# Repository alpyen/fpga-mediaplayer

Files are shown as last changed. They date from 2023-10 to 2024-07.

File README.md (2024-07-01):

# Todos

Stuff that needs to be done, may be incomplete and not in order.

## Project

## HDL
- Video Driver
  - Fifo can contain bits after the last frame has been decoded due to the full byte padding
    - They need to be flushed out before marking playback as done.
      - We need to make sure video_play is low and we encounter an empty video fifo during decoding.
  - Test FSM and generated clock skew over four minutes
- Control Unit
  - Add Generic for the Base Address of the media file
    - This will be useful if we store a media file next to the bitstream or when we want to playback two files
  - Restructure to use less FFs
  - Add check for resolution and don't playback when it's incorrect

## Hardware
- Small LED Board v2
  - TPIC6A595 Open Drain Power Shift Register for low-side switching
  - 74HCT367 Hex-Buffer for level shifting and buffering
  - 74HCT595 instead of 74HC595 to get rid of the level shifters
  - Need to use one wire to disconnect shift register outputs to not overload on unknown power up state
  - No input resistors for shift registers as PMOD JB already has 200 Ohms
  - Pick new high-side MOSFET with low capacitance

## Vivado
- Change the board store in the project-tcl to be OS-independent
- Add custom command to write project tcl
  - add two scripts for loading and storing that just need to be sourced?
- Make sure assertions trigger on synthesis and implementation aswell

## Software
- Codec development
  - Wrap around 4 bit during encoding to save even more space
  - Check if the bitcrushing to 4 bits is correct and compresses uniforly
  - Add resolution to media file

## Documentation
- Write README on how to encode and load up the media file into the board's flash and play it back.

## Compatibility
- Check repo for Ubuntu Linux

# How to open with Vivado

The vivado project has to be regenerated from the project tcl file.
Simply run Vivado and use the tcl console to `cd` into the vivado subfolder of this repository and run `source ./fpga-mediaplayer.tcl`.

If you want to update the tcl file make sure to pass the correct project folder.
Vivado creates a subfolder with the name of the project by default which creates unnecessary nesting so you need to run the tcl command manually.

To write the project tcl make sure you're in the vivado subfolder and run this command: `write_project_tcl -target_proj_dir . fpga-mediaplayer.tcl -force`

Vivado stores absolute paths in the tcl comments, make sure to delete those if you don't want them public.
They can be found at the very top in the big comment.

# Project Goal

This is a personal project to deep dive into FPGA development and get in touch with every part of it
and to learn also a little bit about electrical engineering.

The vision is to have Basys3 board drive a selfmade LED matrix playing back a grayscale video and
outputting sound simultaneously.

Some of the decisions along the way are deliberately made in a non-optimal way such as writing
hdl descriptions for components that already exist to have it done myself and to constrain things.

Topics I want to cover (includes, but is not limited to):
- Develop a full FPGA project with everything necessary
- Write HDL and verify with testbenches
- Write packages and make them accessible
- Make use of existing IP
- Prototyping
- Schematics, Layouting and Manufacturing a PCB
- Interface with other onboard components such as memory
- Interface with prebuilt offboard components such as the Digilent I2S2 PMOD
- Interface with external offboard components such as the LED board
- Work within the limits of the given board such as the Digilent Basys3 (Artix7-35T)
  - 4MB Flash (2MB with configuration)
  - Available IO
  - Clock Speed to maintain realtime
- Software development
  - Codec for audio and video
- Miscellaneous
  - Organization of project structure and repository for Git
  - Documentation of the whole project

Please note that these constraints emerged from the components and devices I have at disposal.
This project could be done with greater resolution and sound output but the goal is to bring it up
and learn everything along the way, that's the reason behind the fullstack approach.

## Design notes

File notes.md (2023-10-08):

# Notes

Contains some thoughts over the development time of the project.

- Is it worth separating the SCK and RCK lines for the row selection shift registers?
  - They could be tied together, all that needs to be done is to clock once more because the data is behind one clock cycle, but it would save one line to the FPGA.
- The small LED board has the IRF4905 P-MOSFET on it, it seems like they are not a good fit, they will be exchanged for the bigger board.
  - They are on there because I ordered them thinking they were a good fit.
  - They work fine but will mess up operating the LEDs at the target voltage/current because the voltage drop changes heavily depending on the current running through it (dependant on how many LEDs are on)
  - Maybe I messed up with the test circuit, I will test again with 32 LEDs for the bigger version when designing that.
- Pullup for logic shifters is 10K which would lead to asymmetrical charge times for the shift registers.
  - See how long it actually takes to charge the lines up with 10K.
- Shift register is CMOS and the inputs have high-impedances so leaving out current limiting resistors.
  - However they are needed for N-MOSFET and P-MOSFET for example (to protect the device that is delivering the current).
  - I think they can be left out if the power supply delivers the current, and not a µC which has output current limitations.
- Pullups for Logic Shifter Drains / Shift Register Inputs are not suitable for the full size board.
  - It seems like it takes a few microseconds to charge up through a 10K, this will be a big problem depending on the video properties. 24fps / 8bpp will need much lower resistor values.
- The small board uses two shift registers for the column selection on purpose even though it could have been implemented with a single one.
  - The only difference to the full size board will be that we are wiring QC to SER from the first to the second register and this only works if the data is present on QC, instead of it only being present in the buffer stage as for example with QH'.

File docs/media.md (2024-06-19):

# Media

This document contains all the information about the mediatype used in this project.

First we identify natural constraints which emerge from the devices and peripheral used. Second we set boundary constraints to limit the scope of this project to something doable.
Lastly there is the specification of the media format.

- [Media](#media)
  - [Constraints](#constraints)
  - [Goals to achieve](#goals-to-achieve)
  - [Specification](#specification)
  - [Codec](#codec)
  - [File Structure](#file-structure)
    - [Header](#header)
    - [Data](#data)

## Constraints
- Digilent Basys3 (Artix7-35T)
- Flash Chip has 4MB/32Mbit of space available
  - Configuration uses 17,536,096 bits
  - with Configuration: 16,018,336 bits (~1,905K)
  - without Configuration: 33,554,432 bits (=4MB)
- Real time decodable for playback
- Do not use existing IP for direct codec implementation
- Decoder (Software counterpart) has to be implemented in hardware
  - therefore the encoder can't be too complex -> sacrificing on compression ratio

## Goals to achieve
- Implementation musn't be linked to loaded media
  - Design should be able to handle all kinds of media configurationswith greater memory capacity can be used easily
- preferrably load from detachable storage (SD-Card, USB-Stick)
- Video:
  - Length: about 4 minutes
  - Resolution: 32 x 24 pixels
  - Framerate: 24 fps
  - Grayscales: 16 shades (4 bits)
- Audio:
  - Length: about 4 minutes
  - Sample Rate: 44,100 Hz
  - Channels: Mono
  - Depth: 16 amplitudes (4 bits)

Calculated file size for uncompressed media:
- Video:
  - 4 mins * 60 * 32 * 24 pixels * 24 fps * 4 bits
  - 17,694,720 bits
- Audio:
  - 4 mins * 60 * 44,100 Hz * 1 * 4 bits
  - 42,336,000 bits
- Total:
  - 60,030,720 bits

Around 134 seconds (2:14) are available without any compression at all if the configuration is not present on the flash.

For the full four minutes, the target file has to be compressed down to 56% of the original file size which will be tough, but achievable.  With the configuration the target file size has to be 26% which is basically impossible for a simple and straight forward codec.

## Specification

## Codec

Since the bitwidth of the audio and video is so low the codec will be very simple.

The codec works by encoding differences over time so we compare the current sample to encode with the previous sample and write the data according to the table.

| Coding Table | Bit representation |
|---|---|
| Current Sample = Previous Sample | 0 |
| Current Sample = Previous Sample + 1 | 1 0 |
| Current Sample = Previous Sample - 1 | 1 1 0 |
| else (none of the above) | 1 1 1 x x x x |

So as an example if the previous sample is a `4` and the current sample is also a `4` we simply write a `0` bit into the encoded file.
For the case where the current sample is `5` we simply write the bits `1 0` into the file indicating that the sample is one higher than the previous saving two bits to the non-encoded counterpart.
For samples that differ too much (e.g. 2 or more) we write `1 1 1` to indicate that the next four bits `x x x x` will define a sample as a whole.

Analysis of some encoded files show that most differences are 0, +-1 and +-2. So even though the last case seems three bits longer than the non-encoded version, it happens less frequently.

For simplicity's sake audio and video will be padded to full bytes.
This only happens at the end of the file!

With the encoding out of the way, let's define a simple file header for the control unit to read out the metadata of the encoded media file.

## File Structure

### Header

``"A" (1B) #AudioBytes (4B) #VideoBytes (4B) "Z" (1B)``

- "A" (1 Byte):
  - This is part of the signature so the control unit can make sure that the contents at the given memory location (to look for the media) is actually a valid encoded file so we don't read garbage. Binary representation in 8-Bit ASCII.
- #AudioBytes (4 Bytes):
  - Little Endian encoded unsigned integer that contains the number of audio bytes contained within the media file.
- #VideoBytes (4 Bytes):
  - Little Endian encoded unsigned integer that contains the number of video bytes contained within the media file.
- "Z" (1 Byte):
  - The end of the signature, analog to the "A". Binary representation in 8-Bit ASCII.

As you can see the header contains no information about the actual encoding or the encoded format since this is irrelevant for the control unit which will only relay the data from the flash to the audio and video drivers.

This is also the key reason why the data is padded to full bytes since we expect the flash to return one byte at a time.

This allows us to vary the encoding without altering the control unit which only needs to read the header.

### Data

Audio and video data follow immediately the header with the complete audio first, then video.
The data is **not** interleaved.

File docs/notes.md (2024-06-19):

# Notes

Contains some thoughts over the development time of the project.

- Is it worth separating the SCK and RCK lines for the row selection shift registers?
  - They could be tied together, all that needs to be done is to clock once more because the data is behind one clock cycle, but it would save one line to the FPGA.
- The small LED board has the IRF4905 P-MOSFET on it, it seems like they are not a good fit, they will be exchanged for the bigger board.
  - They are on there because I ordered them thinking they were a good fit.
  - They work fine but will mess up operating the LEDs at the target voltage/current because the voltage drop changes heavily depending on the current running through it (dependant on how many LEDs are on)
  - Maybe I messed up with the test circuit, I will test again with 32 LEDs for the bigger version when designing that.
- Pullup for logic shifters is 10K which would lead to asymmetrical charge times for the shift registers.
  - See how long it actually takes to charge the lines up with 10K.
- Shift register is CMOS and the inputs have high-impedances so leaving out current limiting resistors.
  - However they are needed for N-MOSFET and P-MOSFET for example (to protect the device that is delivering the current).
  - I think they can be left out if the power supply delivers the current, and not a µC which has output current limitations.
- Pullups for Logic Shifter Drains / Shift Register Inputs are not suitable for the full size board.
  - It seems like it takes a few microseconds to charge up through a 10K, this will be a big problem depending on the video properties. 24fps / 8bpp will need much lower resistor values.
- The small board uses two shift registers for the column selection on purpose even though it could have been implemented with a single one.
  - The only difference to the full size board will be that we are wiring QC to SER from the first to the second register and this only works if the data is present on QC, instead of it only being present in the buffer stage as for example with QH'.
- I think it's worth dividing the memory access, the audio playback, the video playback and the control unit into different modules / entities so they can be interchanged for different implementations such as different memory storages (Flash, SD-Card, USB-Stick) or different codecs.
- The audio and video drivers will be fed through FIFOs and some additional control signals.
- The memory driver does not need a FIFO really.
- Pull all simulations signals to 'U' when they shouldn't be read instead of driving them with '0' for example?
- 'done' was registered in the spi_memory_driver. Is this really necessary? The simulation reacts badly on it, but it should work on hardware?
- Some testbenches could make use of vhdl2008 be pulling out the internal signals as aliases but we're sticking to Vivado's Default for now ('93?)
  - Instead of duplicating the code we simply route the signals outwards, this is ok because none of this will be synthesized so nothing will be wasted.
- I've implemented some ideas for audio codecs which isn't really something that's worth documenting the process of so I'll just implement one and maybe talk about a bit about the other ideas.
- The file header stores the sizes in 4 bytes even though the SPI flash can address at most 3 bytes.
  - This will result in resizing the audio_bytes and video_bytes signal in the control unit to match the 3 bytes address.
- We don't need to save the signature_begin and signature_end in the control unit as they will only be written and read once, it's a waste of flipflops.
- REQUEST_DATA in the control unit only dispatches a request if the read_audio_n_video is set accordingly.
  - This results in one clock cycle loss if for example audio is in order but the audio fifo is full.
  - Then we need to stall for one cycle for the read_audio_n_video signal to change.
  - Technically we could check in the previous state. Does this make sense hardwarewise and timingwise?
- FSM returns to idle when it's done reading audio and video but should only do so when the playback is stopped completely.
- If we calculate the schedule when the modules feed and eat data from the Fifos we could assume some FSM states.
  - Meaning that we for example don't need to check during bit decoding in audio if the Fifo is empty or not.
  - But for safety measures we will still to this, so it's safer when we expand it later down the line to higher quality samples.
  - This is important because the audio and video driver assume the Fifo only to run out **when there is no data left to play**.
- When playing back the 4 bit sample, we are only adding zeroes at the end.
  - We could make it louder by adding almost a bit on it so it maxes out the amplitude.
- CDC_HOLD_COUNT_WIDTH could be calculated more precisely.
  - We are potentially wasting one bit register space.
- The Audio Driver <-> I2S Master machines should never run out of sync that they need a timeout to resync.
- The codec.py calls ffmpeg with the filter `format=gray` instead of `hue=s=0` now. See if that makes a difference down the line.
  - Kept it gray for now since the intermediate files are smaller and will process faster.
- Control/AudioVideoDriver _done signal
  - It is combinational now, is this dangerous? The signal can only change when the state changes so it should work fine. No need to register, right?
- Check if the difference from the expected i2s clock and the actual datasheet clock results in the audio being player slower or faster.
- Do we need to check for reset /= '1' in the frame_buffer?
- The video driver will skew initially by almost up to a full millisecond for the big board, but that is okay, because this skew will not add up over time. The skew increases with resolution but since we don't intend to go higher we can ignore it.
  - However it would be nice to pre-decode the first frame so this skew does not exist.
- Would be nice to structure the project in a way that it's mostly vendor agnostic.

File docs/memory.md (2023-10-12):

# Memory

Notes on the memory driver interfacing with the onboard Macronix MX25L3233F ([Datasheet](https://www.macronix.com/Lists/Datasheet/Attachments/8933/MX25L3233F,%203V,%2032Mb,%20v1.7.pdf)).

> The Digilent Basys3 was manufactured with two different flash chips the other one being the Spansion S25FL032P. I happen to have the one with the Macronix on it. They are similar but not identical. The standard feature set is identical though, so the code can be used for both.

The onboard flash chip has different READ commands, to figure out which one we should use we have to determine
the minimum bandwidth from the media file.

The [Bandwidth minimum](memory.md#goals-to-achieve) is 161,928 bits/s which is 20,241 B/s.
Now we need to calculate the minimum clock frequency for the FPGA to achieve this bandwidth.

The standard READ command `(p.29, 10-7. Read Data Bytes (READ))` needs 8 cycles for the command, 24 cycles for the address and 8 cycles to return the data without pipelining which is 40 cycles in total.

Interfacing the flash chip with 50 MHz is rather dangerous, as stray capacitance (such as hands closeby) can actually disturb the connection and read faulty data, so we use a much safer clock of 10 MHz.
This is a clock that will safely work on-chip and on-board without any interference.

Assuming that we non-stop read data from the flash chip this means that we need to calculate: 10 MHz / 40 cycles/read = 250,000 reads/second.
Since one read will return a byte this will yield an average read-rate of 250 kB/s which is way more than we need.

Macronix offers a verilog simulation model for this chip, but for our use-case it is definitely overkill.
The model only needs to only support the basic READ command and initialize the storage with a given file, it can error out with unsupported commands.

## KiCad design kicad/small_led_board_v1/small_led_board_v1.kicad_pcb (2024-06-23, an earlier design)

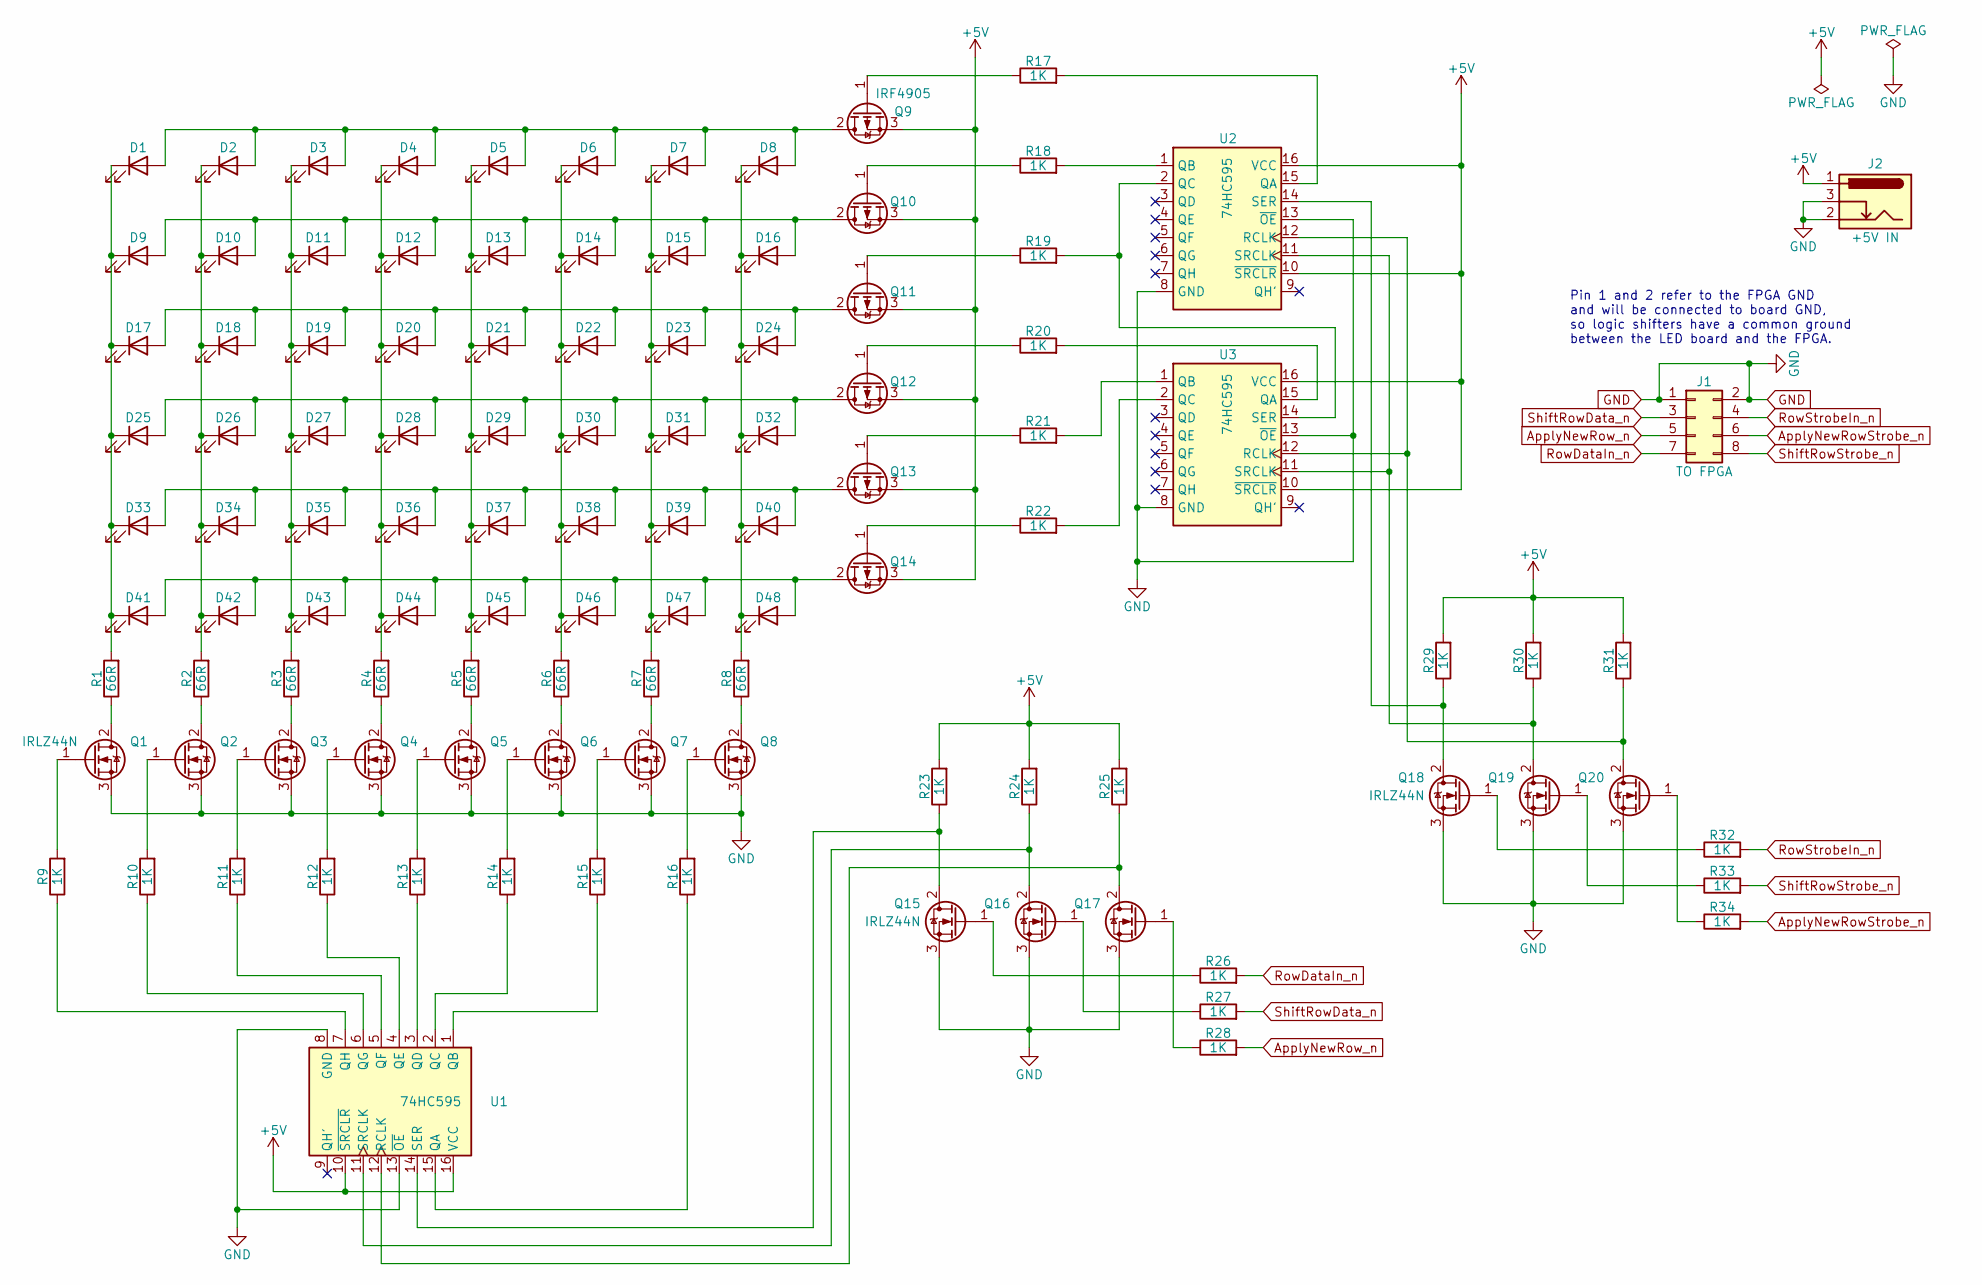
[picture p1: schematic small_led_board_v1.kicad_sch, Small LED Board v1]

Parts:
D1, D2, D3, D4, D5, D6, D7, D8, D9, D10, D11, D12, D13, D14, D15, D16, D17, D18, D19, D20, D21, D22, D23, D24, D25, D26, D27, D28, D29, D30, D31, D32, D33, D34, D35, D36, D37, D38, D39, D40, D41, D42, D43, D44, D45, D46, D47, D48: LED; LED_D5.0mm
J1: TO FPGA; PinSocket_2x04_P2.54mm_Horizontal
J2: +5V IN; BarrelJack_Horizontal
Q1, Q2, Q3, Q4, Q5, Q6, Q7, Q8, Q15, Q16, Q17, Q18, Q19, Q20: IRLZ44N; TO-220-3_Vertical
Q9, Q10, Q11, Q12, Q13, Q14: IRF4905; TO-220-3_Vertical
R1, R2, R3, R4, R5, R6, R7, R8: 66R; R_Axial_DIN0207_L6.3mm_D2.5mm_P7.62mm_Horizontal
R9, R10, R11, R12, R13, R14, R15, R16, R17, R18, R19, R20, R21, R22, R23, R24, R25, R26, R27, R28, R29, R30, R31, R32, R33, R34: 1K; R_Axial_DIN0207_L6.3mm_D2.5mm_P7.62mm_Horizontal
U1, U2, U3: 74HC595; DIP-16_W7.62mm

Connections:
+5V: J2.1, Q9.3 (S), Q10.3 (S), Q11.3 (S), Q12.3 (S), Q13.3 (S), Q14.3 (S), R23.2, R24.2, R25.2, R29.2, R30.2, R31.2, U1.10 (~SRCLR), U1.16 (VCC), U2.10 (~SRCLR), U2.16 (VCC), U3.10 (~SRCLR), U3.16 (VCC)
ApplyNewRowStrobe_n: J1.6, R34.2
ApplyNewRow_n: J1.5, R28.2
GND: J1.1, J1.2, J2.2, J2.3, Q1.3 (S), Q2.3 (S), Q3.3 (S), Q4.3 (S), Q5.3 (S), Q6.3 (S), Q7.3 (S), Q8.3 (S), Q15.3 (S), Q16.3 (S), Q17.3 (S), Q18.3 (S), Q19.3 (S), Q20.3 (S), U1.8 (GND), U1.13 (~OE), U2.8 (GND), U2.13 (~OE), U3.8 (GND), U3.13 (~OE)
unnamed: D1.2 (A), D2.2 (A), D3.2 (A), D4.2 (A), D5.2 (A), D6.2 (A), D7.2 (A), D8.2 (A), Q9.2 (D)
unnamed: D1.1 (K), D9.1 (K), D17.1 (K), D25.1 (K), D33.1 (K), D41.1 (K), R1.2
unnamed: D9.2 (A), D10.2 (A), D11.2 (A), D12.2 (A), D13.2 (A), D14.2 (A), D15.2 (A), D16.2 (A), Q10.2 (D)
unnamed: D2.1 (K), D10.1 (K), D18.1 (K), D26.1 (K), D34.1 (K), D42.1 (K), R2.2
unnamed: D3.1 (K), D11.1 (K), D19.1 (K), D27.1 (K), D35.1 (K), D43.1 (K), R3.2
unnamed: D4.1 (K), D12.1 (K), D20.1 (K), D28.1 (K), D36.1 (K), D44.1 (K), R4.2
unnamed: D5.1 (K), D13.1 (K), D21.1 (K), D29.1 (K), D37.1 (K), D45.1 (K), R5.2
unnamed: D6.1 (K), D14.1 (K), D22.1 (K), D30.1 (K), D38.1 (K), D46.1 (K), R6.2
unnamed: D7.1 (K), D15.1 (K), D23.1 (K), D31.1 (K), D39.1 (K), D47.1 (K), R7.2
unnamed: D8.1 (K), D16.1 (K), D24.1 (K), D32.1 (K), D40.1 (K), D48.1 (K), R8.2
unnamed: D17.2 (A), D18.2 (A), D19.2 (A), D20.2 (A), D21.2 (A), D22.2 (A), D23.2 (A), D24.2 (A), Q11.2 (D)
unnamed: D25.2 (A), D26.2 (A), D27.2 (A), D28.2 (A), D29.2 (A), D30.2 (A), D31.2 (A), D32.2 (A), Q12.2 (D)
unnamed: D33.2 (A), D34.2 (A), D35.2 (A), D36.2 (A), D37.2 (A), D38.2 (A), D39.2 (A), D40.2 (A), Q13.2 (D)
unnamed: D41.2 (A), D42.2 (A), D43.2 (A), D44.2 (A), D45.2 (A), D46.2 (A), D47.2 (A), D48.2 (A), Q14.2 (D)
unnamed: Q1.2 (D), R1.1
unnamed: Q1.1 (G), R9.2
unnamed: Q2.2 (D), R2.1
unnamed: Q2.1 (G), R10.2
unnamed: Q3.2 (D), R3.1
unnamed: Q3.1 (G), R11.2
unnamed: Q4.2 (D), R4.1
unnamed: Q4.1 (G), R12.2
unnamed: Q5.2 (D), R5.1
unnamed: Q5.1 (G), R13.2
unnamed: Q6.2 (D), R6.1
unnamed: Q6.1 (G), R14.2
unnamed: Q7.2 (D), R7.1
unnamed: Q7.1 (G), R15.2
unnamed: Q8.2 (D), R8.1
unnamed: Q8.1 (G), R16.2
unnamed: Q9.1 (G), R17.1
unnamed: Q10.1 (G), R18.1
unnamed: Q11.1 (G), R19.1
unnamed: Q12.1 (G), R20.1
unnamed: Q13.1 (G), R21.1
unnamed: Q14.1 (G), R22.1
unnamed: Q15.2 (D), R23.1, U1.14 (SER)
unnamed: Q15.1 (G), R26.1
unnamed: Q16.2 (D), R24.1, U1.11 (SRCLK)
unnamed: Q16.1 (G), R27.1
unnamed: Q17.2 (D), R25.1, U1.12 (RCLK)
unnamed: Q17.1 (G), R28.1
unnamed: Q18.2 (D), R29.1, U2.14 (SER)
unnamed: Q18.1 (G), R32.1
unnamed: Q19.2 (D), R30.1, U2.11 (SRCLK), U3.11 (SRCLK)
unnamed: Q19.1 (G), R33.1
unnamed: Q20.2 (D), R31.1, U2.12 (RCLK), U3.12 (RCLK)
unnamed: Q20.1 (G), R34.1
unnamed: R16.1, U1.15 (QA)
unnamed: R15.1, U1.1 (QB)
unnamed: R14.1, U1.2 (QC)
unnamed: R13.1, U1.3 (QD)
unnamed: R12.1, U1.4 (QE)
unnamed: R11.1, U1.5 (QF)
unnamed: R10.1, U1.6 (QG)
unnamed: R9.1, U1.7 (QH)
unnamed: R17.2, U2.15 (QA)
unnamed: R18.2, U2.1 (QB)
unnamed: R19.2, U2.2 (QC), U3.14 (SER)
unnamed: R20.2, U3.15 (QA)
unnamed: R21.2, U3.1 (QB)
unnamed: R22.2, U3.2 (QC)
RowDataIn_n: J1.7, R26.2
RowStrobeIn_n: J1.4, R32.2
ShiftRowData_n: J1.3, R27.2
ShiftRowStrobe_n: J1.8, R33.2

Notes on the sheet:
Pin 1 and 2 refer to the FPGA GND and will be connected to board GND, so logic shifters have a common ground between the LED board and the FPGA.

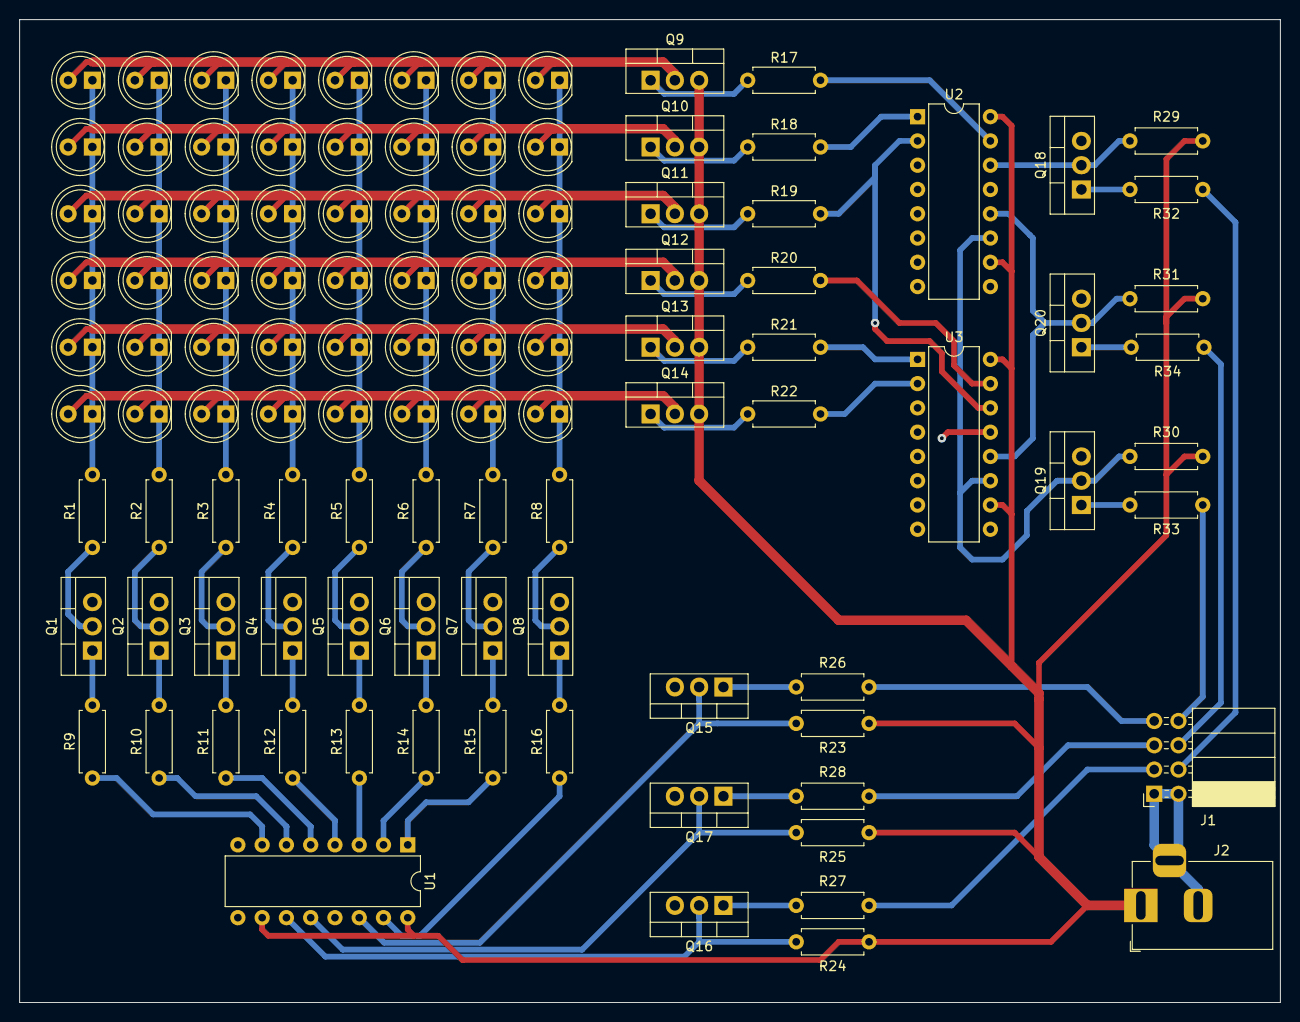
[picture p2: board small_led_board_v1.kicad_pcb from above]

Board: 2 copper layers, 132.0 x 102.9 mm, 107 parts (0 on the bottom side), 70 nets.

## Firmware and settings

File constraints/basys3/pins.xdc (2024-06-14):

## Clock signal
set_property -dict { PACKAGE_PIN W5   IOSTANDARD LVCMOS33 } [get_ports clock100mhz];

## Switches
# set_property -dict { PACKAGE_PIN V17   IOSTANDARD LVCMOS33 } [get_ports {sw[0]}];
# set_property -dict { PACKAGE_PIN V16   IOSTANDARD LVCMOS33 } [get_ports {sw[1]}];
# set_property -dict { PACKAGE_PIN W16   IOSTANDARD LVCMOS33 } [get_ports {sw[2]}];
# set_property -dict { PACKAGE_PIN W17   IOSTANDARD LVCMOS33 } [get_ports {sw[3]}];
# set_property -dict { PACKAGE_PIN W15   IOSTANDARD LVCMOS33 } [get_ports {sw[4]}];
# set_property -dict { PACKAGE_PIN V15   IOSTANDARD LVCMOS33 } [get_ports {sw[5]}];
# set_property -dict { PACKAGE_PIN W14   IOSTANDARD LVCMOS33 } [get_ports {sw[6]}];
# set_property -dict { PACKAGE_PIN W13   IOSTANDARD LVCMOS33 } [get_ports {sw[7]}];
# set_property -dict { PACKAGE_PIN V2    IOSTANDARD LVCMOS33 } [get_ports {sw[8]}];
# set_property -dict { PACKAGE_PIN T3    IOSTANDARD LVCMOS33 } [get_ports {sw[9]}];
# set_property -dict { PACKAGE_PIN T2    IOSTANDARD LVCMOS33 } [get_ports {sw[10]}];
# set_property -dict { PACKAGE_PIN R3    IOSTANDARD LVCMOS33 } [get_ports {sw[11]}];
# set_property -dict { PACKAGE_PIN W2    IOSTANDARD LVCMOS33 } [get_ports {sw[12]}];
# set_property -dict { PACKAGE_PIN U1    IOSTANDARD LVCMOS33 } [get_ports {sw[13]}];
# set_property -dict { PACKAGE_PIN T1    IOSTANDARD LVCMOS33 } [get_ports {sw[14]}];
# set_property -dict { PACKAGE_PIN R2    IOSTANDARD LVCMOS33 } [get_ports {sw[15]}];


## LEDs
# You cannot leave driven top level pins unplaced, but we need spi_sclk for the testbench.
# Since we don't need it on the Artix7 (as it is accessed through STARTUPE2) we simply
# output it somewhere where it doesn't really bother us.
set_property -dict { PACKAGE_PIN U16   IOSTANDARD LVCMOS33 } [get_ports spi_sclk]; # led0
# set_property -dict { PACKAGE_PIN E19   IOSTANDARD LVCMOS33 } [get_ports {led[1]}];
# set_property -dict { PACKAGE_PIN U19   IOSTANDARD LVCMOS33 } [get_ports {led[2]}];
# set_property -dict { PACKAGE_PIN V19   IOSTANDARD LVCMOS33 } [get_ports {led[3]}];
# set_property -dict { PACKAGE_PIN W18   IOSTANDARD LVCMOS33 } [get_ports {led[4]}];
# set_property -dict { PACKAGE_PIN U15   IOSTANDARD LVCMOS33 } [get_ports {led[5]}];
# set_property -dict { PACKAGE_PIN U14   IOSTANDARD LVCMOS33 } [get_ports {led[6]}];
# set_property -dict { PACKAGE_PIN V14   IOSTANDARD LVCMOS33 } [get_ports {led[7]}];
# set_property -dict { PACKAGE_PIN V13   IOSTANDARD LVCMOS33 } [get_ports {led[8]}];
# set_property -dict { PACKAGE_PIN V3    IOSTANDARD LVCMOS33 } [get_ports {led[9]}];
# set_property -dict { PACKAGE_PIN W3    IOSTANDARD LVCMOS33 } [get_ports {led[10]}];
# set_property -dict { PACKAGE_PIN U3    IOSTANDARD LVCMOS33 } [get_ports {led[11]}];
# set_property -dict { PACKAGE_PIN P3    IOSTANDARD LVCMOS33 } [get_ports {led[12]}];
# set_property -dict { PACKAGE_PIN N3    IOSTANDARD LVCMOS33 } [get_ports {led[13]}];
# set_property -dict { PACKAGE_PIN P1    IOSTANDARD LVCMOS33 } [get_ports {led[14]}];
# set_property -dict { PACKAGE_PIN L1    IOSTANDARD LVCMOS33 } [get_ports {led[15]}];


##7 Segment Display
# set_property -dict { PACKAGE_PIN W7   IOSTANDARD LVCMOS33 } [get_ports {seg[0]}];
# set_property -dict { PACKAGE_PIN W6   IOSTANDARD LVCMOS33 } [get_ports {seg[1]}];
# set_property -dict { PACKAGE_PIN U8   IOSTANDARD LVCMOS33 } [get_ports {seg[2]}];
# set_property -dict { PACKAGE_PIN V8   IOSTANDARD LVCMOS33 } [get_ports {seg[3]}];
# set_property -dict { PACKAGE_PIN U5   IOSTANDARD LVCMOS33 } [get_ports {seg[4]}];
# set_property -dict { PACKAGE_PIN V5   IOSTANDARD LVCMOS33 } [get_ports {seg[5]}];
# set_property -dict { PACKAGE_PIN U7   IOSTANDARD LVCMOS33 } [get_ports {seg[6]}];

# set_property -dict { PACKAGE_PIN V7   IOSTANDARD LVCMOS33 } [get_ports dp];

# set_property -dict { PACKAGE_PIN U2   IOSTANDARD LVCMOS33 } [get_ports {an[0]}];
# set_property -dict { PACKAGE_PIN U4   IOSTANDARD LVCMOS33 } [get_ports {an[1]}];
# set_property -dict { PACKAGE_PIN V4   IOSTANDARD LVCMOS33 } [get_ports {an[2]}];
# set_property -dict { PACKAGE_PIN W4   IOSTANDARD LVCMOS33 } [get_ports {an[3]}];


##Buttons
# set_property -dict { PACKAGE_PIN U18   IOSTANDARD LVCMOS33 } [get_ports btnC];
# set_property -dict { PACKAGE_PIN T18   IOSTANDARD LVCMOS33 } [get_ports btnU];
set_property -dict { PACKAGE_PIN W19   IOSTANDARD LVCMOS33 } [get_ports reset]; # btnL
set_property -dict { PACKAGE_PIN T17   IOSTANDARD LVCMOS33 } [get_ports start_button]; # btnR
# set_property -dict { PACKAGE_PIN U17   IOSTANDARD LVCMOS33 } [get_ports btnD];
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

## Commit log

2023-09-28 small_led_board: Update schematics
    [small_led_board.kicad_pcb, small_led_board.kicad_sch]
2023-09-28 small_led_board: Schematic updated, DRC pass
    - Schematic passes DRC check without any issue
    - LED resistors still need to be calculated after that the schematic should be finished
    [small_led_board.kicad_pcb, small_led_board.kicad_sch]
2023-09-29 small_led_board: Schematics done
    [small_led_board.kicad_sch]
2023-09-29 small_led_board: PCB started
    [small_led_board.kicad_pcb, small_led_board.kicad_sch]
2023-09-29 small_led_board: Placed and Routed PCB
    [small_led_board.kicad_pcb, small_led_board.kicad_sch]
2023-10-02 small_led_board: Changed PCB settings
    Constraints were originally pulled from a git template project.
    Changed 4 layers to 2 layers as only Front and Back are needed.
    [small_led_board.kicad_pcb]
2023-10-06 Update: Small board done
    The small board has been soldered and can be driven flawlessly from the digital pins of an Arduino.
2023-10-07 small_led_board: Renamed pin for more consistency
    [small_led_board.kicad_pcb, small_led_board.kicad_sch]
2023-10-08 hdl: Added testbench for the small led board
    Rudimentary testbench to see if it works alright, the testbenches for the actual hdl will be more involved.
    Fixed a forgotten not for the small led board.
2023-10-12 hdl: Starting work on the spi flash functional model
2023-10-13 hdl: Started SPI flash model and testbench
2023-10-15 hdl: SPI flash model and test bench done
2023-10-15 hdl: SPI Memory Driver implemented and tested
    Not certain if some signals need to be clocked or not.
    The simulation kinda differs from the real hardware so we'll implement a basic TLE to test it on the board.
2023-10-16 hdl: Added debouncer entity Writing a top-level-entity for board testing the spi memory driver.
2023-10-16 Updated gitignore to track IP xci-files
2023-10-16 hdl: Top-Level-Entity for SPI Memory Driver Board Test Added and successfully tested a tle to use the memory driver on the Basys3 board. Organized constraints a bit better. Updated project-tcl.
2023-11-22 Refactoring: WIP, Unifying Testbenches
    Testbenches will not be separated anymore, instead the whole device will be tested and the periphery such as memory, led board, audio board will be attached to the testbench.
2023-11-22 sim: Wired up forgotten SPI clock in testbench case
2023-11-25 hdl: Control Unit dispatches start signal, Audio Driver next
2023-11-25 hdl: Audio Driver started
2023-11-26 codec: Switched out ultrashort loop
    The old one did not cover the whole codec spectrum, this one does.
2023-11-26 Audio Driver: Started, comb. loop needs fixing
    decoding_start and decoding_done are interfering with one another
2023-11-28 codec: Fixed broken new sample and recoded test files
2023-12-01 I2S Master: Clocking out data, Transfer to Audio Driver next
2023-12-04 Audio Driver: Transfer FSM implemented and simulated
    Simulation looks good so far, needs some thorough analysis and then a test with the I2S board can be done.
2023-12-05 XDC: Disabled timing between separate clocks and updated project file
    Fixed the reset of the i2s_master's new sample fifo. It used to unsynchronized signal.
2024-03-09 video driver: added fifo, pin constraints and implementation stub
    refactored some code, renamed for better semantics
2024-03-09 media: added sample 8x6 encoded file
    the scripts are still hardcoded to 32x24, maybe that will change in the future, for now one 8x6 file should suffice for testing
2024-03-09 control unit: fixed stuck in state when preloading
    this was due to not checking if the audio fifo for example was filled with all samples and we tried to switch from video to audio
2024-03-11 frame buffer: implemented frame buffer memory
2024-03-20 video driver: added frame buffer
2024-06-05 clock calculator: jitter constraining added
2024-06-05 clock calculator: renamed jitter to sub clock deviation
2024-06-05 clock calculator: removed
    The idea is good for a device that doesn't care whether the two sub clocks can differ so much within a second but in our case this is useless.
    That's because it would mean that half the second the video runs for example 10% slower, and half the second 10% faster.
2024-06-07 video driver: phase accumulator implemented for video timing
2024-06-08 video driver: refactoring and added new components
    Pulled out the logic to drive the board towards board_driver.vhdl.
2024-06-12 misc: readme update and refactor
    Implementation of the video_driver and board_driver coming up now. After this it should be ready to be tested on the actual prototype board.
2024-06-12 frame buffer: added output registers
    This was an oversight, they were always meant to be registered. It came up when simulating the video driver.
2024-06-12 video driver: implemented decoding
2024-06-13 video driver: various fixes
    - Registered board_driver_frame_available, the logic for this is incomplete though. It has to be set in the decoder_fsm, and reset in the fsm. Remarked in notes.md
    - Moved selected_buffer toggle to different location.
    - Fixed the default value of new_pixel_value_next to be previous value so it survives state transitions.
2024-06-14 constraints: fixed row selection pins
    They were one shifted down which looks funny on the dev board.
    [pins.xdc]
2024-06-14 frame buffer: split data_a inout port to two separate ports
    - Changed the video driver alongside it
2024-06-16 video driver: fixed incorrect port assignment
2024-06-18 video driver: fixed decoding for first frame
2024-06-18 board driver: implemented completely, works too!
    - A board test has been completed successfully simultaneously playing back audio and video! However it seems that we are clocking too fast for the current configuration so the design has to be altered. (like lower resistance pullups)
    - Next commit will be detailed update of the README.md and some notes.
2024-06-19 frame buffer: memory inferring BRAM now
    Before the synthesis tool was not able to infer BRAM as the description was not mappable on it. I've restructured the code, removed the memory reset (which is not necessary).
    While it was not really necessary for the 8x6 board, the 32x24 board consumes about 30% of the totally available LUTs which is inacceptable.
2024-06-19 video driver: fixed reading previous frame when reading first frame
    This way we don't have to reset the frame buffers back to zero before decoding video data. We had to do either of them otherwise it will corrupt the whole playback.
2024-06-19 board driver: fixed missing x-pixel counter reset, updated clock calculation
    This error flew under the radar because the small board's size is eight which is a multiple of two so the counter perfectly overflows back to zero when a row is done.
    However it does not work for the full size board.
2024-06-19 kicad: updated resistor values to 1K
    The small led board was barely managing to charge up the shift registers' lines with 10K without any additional strobing.
    Now with this change in place, they can strobe four times easily. This is still not nearly the target we want to reach, but it's a first improvement.
    [small_led_board.kicad_pcb, small_led_board.kicad_sch]
2024-06-23 kicad: migrate to kicad 8.0
    [small_led_board.kicad_pcb, small_led_board.kicad_sch]
2024-06-27 readme: small led board will be revised
2024-06-28 kicad: renamed project to v1
    [small_led_board_v1.kicad_pcb, small_led_board_v1.kicad_sch]
2024-07-01 small led board v2: progress on schematics
    This is a wip, part selection is most likely final but wiring is subject to change and pcb layout has not been started.
    [small_led_board_v2.kicad_pcb, small_led_board_v2.kicad_sch]
2024-07-01 small led board v2: schematics done for now
    [small_led_board_v2.kicad_sch]
